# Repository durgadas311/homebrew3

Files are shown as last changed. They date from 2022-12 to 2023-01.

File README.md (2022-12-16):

# homebrew3

This project is for this
[VCFED discussion thread](https://forum.vcfed.org/index.php?threads/homebrew-z80-no-3.1240919/).

Photos of the computer are on this
[Google Drive](https://drive.google.com/drive/folders/1JXV017_ggF-4IG32N2BlPU1Jmj1P-w-M).

Documentation:

 * [Schematics](kicad/homebrew3.pdf)
 * [Layout/BOM](kicad/perfboard-layout.pdf)
 * [Monitor ROM](doc/MonitorROM.pdf)
 * [Simulator Help](https://htmlpreview.github.io/?https://github.com/durgadas311/homebrew3/blob/master/sim/docs/HB3.html)

The "gui" option (or property) is now working.

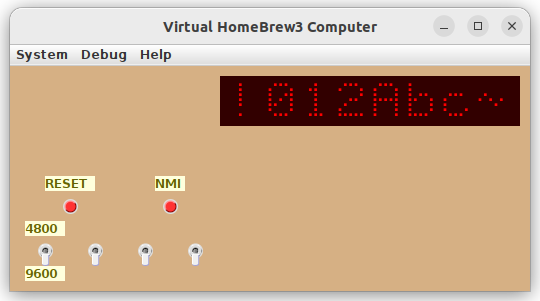
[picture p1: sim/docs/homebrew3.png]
HB3 pic


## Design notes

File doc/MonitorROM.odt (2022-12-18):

Z80 Home Brew #3

Monitor ROM

December 18, 2022

## Overview

The machine consists of a Z80-CPU, 2K EPROM (expandable to 4K), 4K of RAM, two Z80-PIO, one Z80CTC, one Z80-SIO/0, and an HDSP-2111 8-character 5x7 LED dot matrix display. All four PIO channels are wired to a 50-pin FCC connector (P3). Both SIO channels are wired to a DIP14 socket/connector (P4). General-purpose I/O expansion is provided on a pair of DIP14 sockets/connectors (P1, P2). The HDSP-2111 display is wired as an I/O expansion.

The original EPROM for this machine was damaged, and all odd pages (256-byte chunks) are missing (A8 shorted to GND). Half the monitor code is missing, but some things can be reconstructed or restored based how the existing code interacts.

## General Operation

The monitor may be entered from a running program by pressing the NMI button or by executing a RST 1 instruction (0xCF) in the program. In the case of RST 1, the saved PC will point to the RST 1 instruction (not the next instruction). In both cases, the saved PC is printed after a ‘>’ character before entering the monitor loop.

Pressing NMI while running the monitor is similar to RESET.

The monitor prompt is the asterisk (‘*’) character, however that is reconstructed code and there is no indication what the prompt character was originally.

## User Commands

In the following, addr and byte are entered in hexadecimal. [ ] means the parameter is optional. CR means the carriage return key. LF means the line feed key.

### Implemented Commands

The following commands either have code that defines the operation, or can be reasonably determined based on space available and logical deduction.

[addr]CR

print the byte stored at addr, advance addr by 1.

[addr]/

print the word stored at addr, advance addr by 2. Also used after ‘T’ or ‘R’ commands to view subsequent values.

[addr]I

Input bytes starting at addr. Prints current address and current contents and waits for input. Commands are:

[byte]CR

store byte (if entered) in addr, increment addr by 1. CR alone is used to skip to next location without altering contents.

decrement addr by 1.

return to monitor

[addr]G

Go (start execution) at addr or saved PC

P

start execution at PC+1 (for continuing after RST 1 traps).

T

print word at saved SP (top of stack), increment addr by 2. The top of stack will not include the PC that was pushed as part of the NMI or RST 1. The rest of the stack may be viewed by using ‘/’ commands.

Rreg/

print contents of saved register pair. reg is one of: A,B,D,H,A',B',D',H',X,Y,S,P. Increment addr by 2, effectively selecting the next register pair. Successive registers may be viewed by using ‘/’ commands.

H

Host control mode? Appears to accept commands from SIO channel B, as if connected to a remote computer. Remote commands are echoed to console (channel A), unclear what other interaction there is. Or possibly just an alternate set of commands still using the console (current implementation, for testing).

### Unknown Commands

The following commands do not have code.

LF

(unknown)

^

(unknown) “up”?

V

(unknown) “down”?

## Host Control Commands

Host control commands may be prefixed with an octal number. Unclear how data is sent back to host (in octal?). Might still be controlled by console, unclear if any interaction with host.

(unknown)

,

(unknown)

\

(unknown)

LF

(unknown)

CR

(unknown)

S

(unknown)

R

(unknown)

X

Exit Host mode, return to monitor

M

(unknown interaction with PIO-connected device) possible device memory test

/

(unknown)

^

(unknown)

<

(unknown)

>

(unknown)

G

Get 2K bytes from PIO-connected device. Read pairs of 4-bits from PIO2B. Buffer at 1600H. Missing routines to initialize and perform actions between each 4-bits.

P

Put 2K bytes to PIO-connected device. Writes pairs of 4-bits to PIO2A. Buffer at 1600H. Missing routines to initialize and perform actions between each 4-bits.

TBD

enter Terminal mode, with HEX loading enabled.

[addr]TBD

write addr to the PIO-connected device as two 6-bit values on pio1A, strobing pio2B bit 4 for low value and pio2B bit 5 for high value. The value addr is first decremented by 2 and xor’ed with 1. Any bits beyond the 12 are ignored.

## Terminal Mode Operation

The code passes characters both directions between SIO channels A and B. In addition, there is a mode where the stream coming from channel B may contain Intel HEX format data, which is presumably loaded into memory. The console (channel A) user may press Ctrl-] (0x1d, ASCII “GS”) to cause a BREAK condition to be sent to channel B, presumably to disconnect from the host or terminate a program. There is some number of successive Ctrl-] presses required to activate the BREAK feature, to avoid accidental disconnect. At least one other key command seems to exist, possibly to exit terminal mode. Considering the nature of “terminal mode”, this exit key would have been some control character that is not normally used (similar to the BREAK code).

## Hardware Clues in Software

### Device on 50-pin Connector

- Data path seems to be 4-bits wide, output on low bits of PIO2-A and input on low bits of PIO2-B.
- There may be a 6-bit path, sometimes used for address hi/lo, on PIO1-A.
- Capacity seems to be 2K bytes (4K nibbles).
- Addressing seems to be 12-bit, with the LSB selecting the nibble.
  - In one case, the user-entered address is modified before sending: addr = (addr – 2) ^ 1, and 6-bit halves are successively sent to PIO1-A while pulsing PIO2-B bits 4 and 5 (for low and high halves, respectively).
- There seems to be either RAM associated with the device (e.g. a buffered EPROM programmer) or else the device allows plugging in of RAM chips (e.g. an IC tester).
- There is a subset of commands that operate on this device, activated by the ‘H’ command.
- These subcommands use octal, in contrast to the main monitor commands that use hexadecimal. Although, parameters that might be input for various commands may use some other base (the code is missing).
- In some cases, it appears that the PIO RDY outputs are used by the device to latch data, but in one case (at least) PIO2-B bits 4 and 5 are bit-banged to latch data (from PIO1-A). Note that, in order for RDY to be effective, the /STB inputs must also be used.
- The ‘H’ subcommand mode programs PIO1-A, PIO1-B, and PIO2-A in output mode (RDY signals active), and programs PIO2-B in control mode with bits 0-3 as inputs, 4-7 as outputs.

### LED 5x7 Display

- No code has been found that accesses the display. It may have been added for experimentation purposes (vs. being part of the development environment).
- This display is capable of showing eight ASCII characters (full 7-bit decoding).
- The display datecode indicates 1987, while the rest of the parts have datecodes 1977-1981. It is possible that the display is not part of the original equipment. The wire-wrap shows that that device was added last (in that vicinity).
- It is possible that the display was used to mirror console output or show some other status, but that would have to be in the missing code.

### Serial Ports

- SIO-A is the user console. Unclear if that was a hard-copy like ASR-33 or a CRT terminal.
- Under some conditions, SIO-B is connected to a remote system (“terminal mode”).
- The only confirmed code to use SIO-B is the terminal mode loop.
- It is not known if the 4800/9600 switch affects SIO-A or SIO-B. It would depend on what each is connected to, e.g. an ASR-33 on A can only be 110 baud, so 4800/9600 must be SIO-B. But if SIO-B connects to a modem, then 4800/9600 must be for SIO-A (given the time period and modem speeds of that era). The actual data used to program SIO bauds is missing.
- All four toggle switches feed to the handshake inputs on the SIO. The only code known to access those inputs is the test for 4800/9600 done during initialization.
- The original connections to the SIO were via 4-wire modular telephone cable (YEL, GRN, RED, BLK). Channel B is wired reverse from channel A (RxD/TxD).
  - There appears to have been one wire that was passed through directly between port A and Port B, probably a handshake line. Unclear which direction or purpose. ‘?’ below.
  - One port’s cable terminated in a RJ14-M modular connector, the other terminated in a RJ14-F mounted in the terminal box, painted blue. Unclear which port went to which connector. Also unclear how each cable was wired to the RJ14 connector.
  - Port A is wired TxD=YEL, RxD=RED, ?=GRN, GND=BLK.
  - Port B is wired TxD=RED, RxD=YEL, ?=GRN, GND=BLK.
  - It is not known whether the original owner had “standard” RJ14-to-RS232 adapters, or used some custom connections to the end points.

Z80 home Brew #3 – Monitor ROM 6

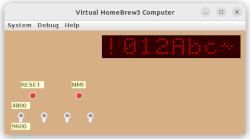
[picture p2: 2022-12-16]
sim/docs/homebrew3-sm.png

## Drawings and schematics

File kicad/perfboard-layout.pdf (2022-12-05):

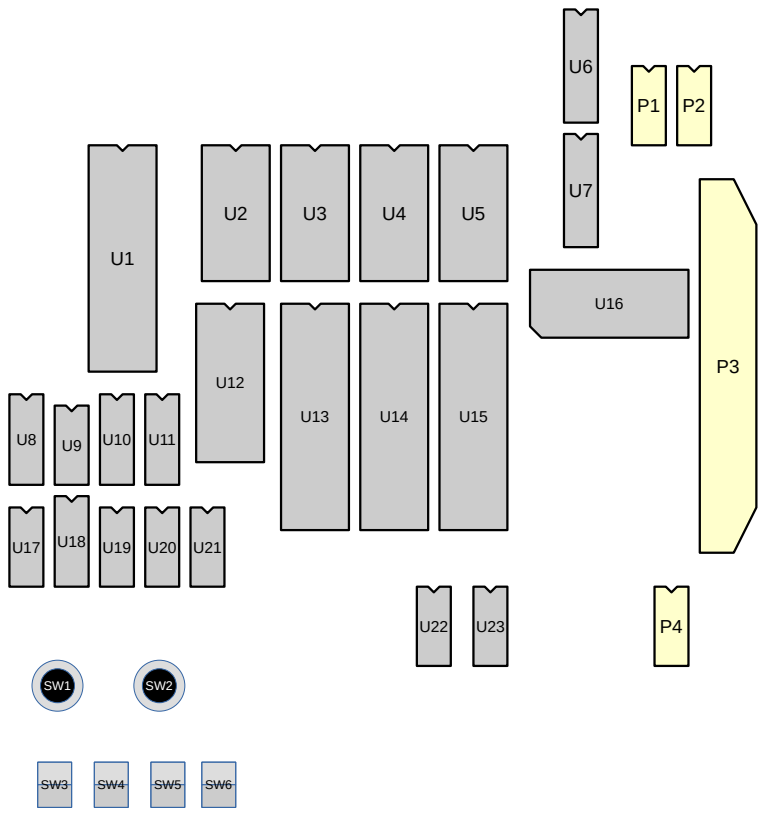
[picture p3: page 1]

U1 | Z80A-CPU
U2 | MK2716 (@0000)
U3 | MK2716 (@0800) – empty
U4 | TMM2016 (@1000)
U5 | TMM2016 (@1800)
U6 | 74LS245
U7 | 74LS245
U8 | 74S163
U9 | 74S04
U10 | 74LS138
U11 | 74LS139
U12 | Z80A-CTC
U13 | Z80A-SIO/0
U14 | Z80A-PIO
U15 | Z80A-PIO
U16 | HDSP-2111 (5x7 8-char display)
U17 | 20.000MHz Oscillator
U18 | Discrete components:
R1: | 1,16 | 330 R
R2: | 2,15 | 33K R
D1: | +3,14 D
R3: | 4,13 | 68 R
C1: | +5,12 C (electrolytic)
| 6,11 | empty
R4: | 7,10 | 5.6K R
| 8,9 | empty
U19 | 74LS14
U20 | 74LS08
U21 | 74LS32
U22 | MC1489
U23 | MC1488
SW1 | SPDT pushbutton – RESET
SW2 | SPDT pushbutton – NMI
SW3 SPDT toggle – 4800/9600 (up/down)
SW4 | SPDT toggle
SW5 | SPDT toggle
SW6 SPDT toggle
P1 | DIP14 socket – I/O expansion
P2 | DIP14 socket – I/O expansion
P3 | FCC50-M – GPIO (Z80A-PIOs)
P4 | DIP14 socket – RS-232

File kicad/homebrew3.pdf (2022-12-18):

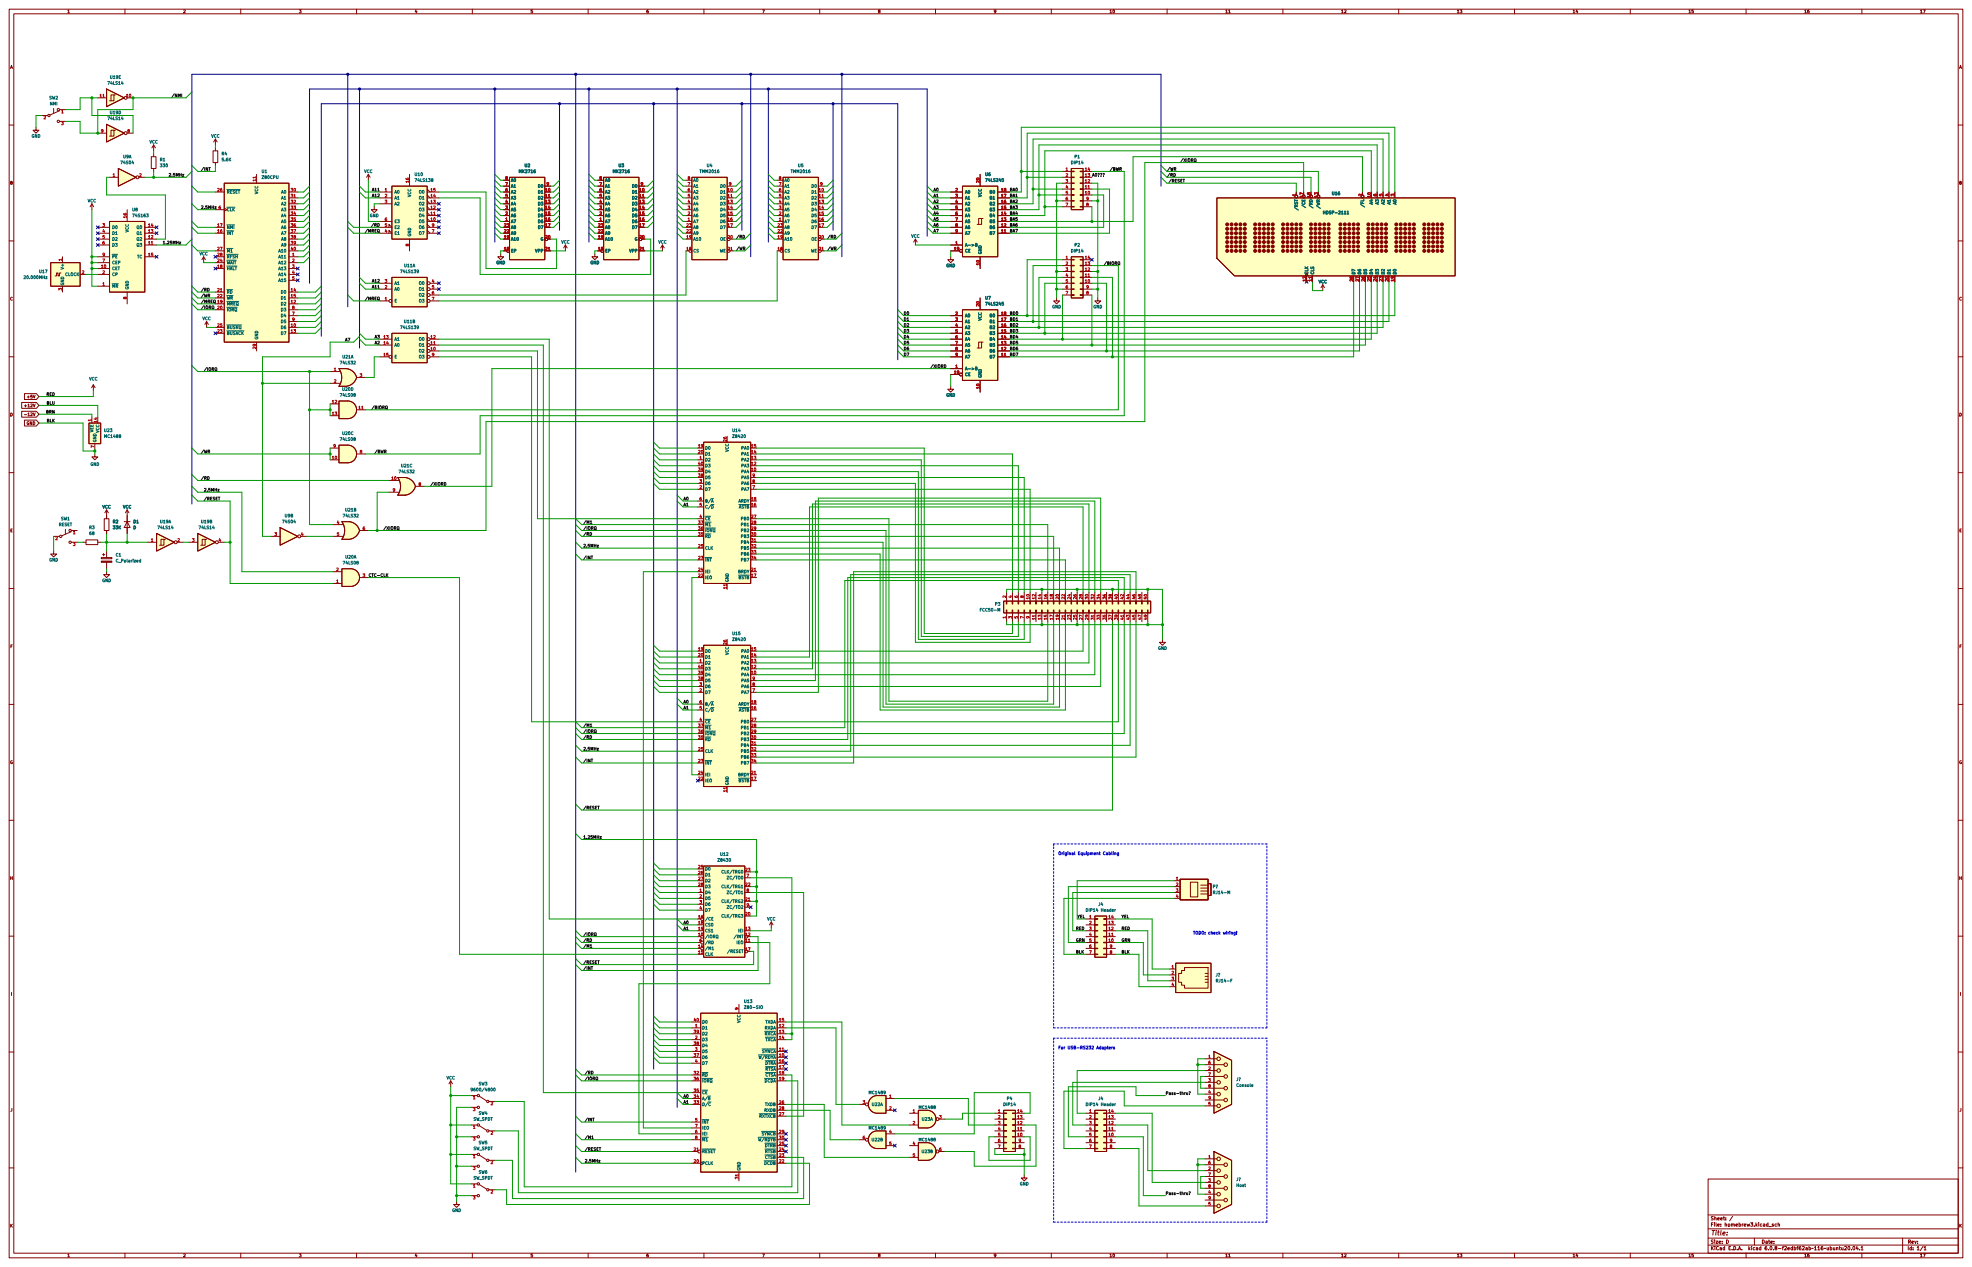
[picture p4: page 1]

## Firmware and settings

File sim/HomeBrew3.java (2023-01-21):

// Copyright 2018 Douglas Miller <durgadas311@gmail.com>

import java.util.Arrays;
import java.util.Vector;
import java.util.Map;
import java.util.HashMap;
import java.io.*;
import java.util.concurrent.Semaphore;
import java.util.concurrent.locks.ReentrantLock;
import java.util.Properties;

import z80core.*;
import z80debug.*;

public class HomeBrew3 implements Computer, ComputerSystem,
			Commander, Interruptor, Runnable {
	private Z80 cpu;
	private Z80SIO sio;
	private long clock;
	private Map<Integer, IODevice> ios;
	private Vector<IODevice> devs;
	private Vector<DiskController> dsks;
	private Vector<InterruptController> intrs;
	private Memory mem = null;
	private boolean running;
	private boolean stopped;
	private Semaphore stopWait;
	private int[] intRegistry;
	private int[] intLines;
	private int intState;
	private int intMask;
	private boolean nmiState;
	private boolean isHalted;
	private boolean sleeping;
	private Vector<ClockListener> clks;
	private CPUTracer trc;
	private StdioDebugger dbg;
	private ReentrantLock cpuLock;

	private int mdmA = 0;
	private int mdmB = 0;

	// Relationship between virtual CPU clock and real time
	private long intervalTicks = 2500;	// 1ms at 2.5MHz
	private long intervalNs = 1000000;	// 1ms
	private long backlogTime = 10000000;	// 10ms backlog limit
	private long backlogNs;

	public HomeBrew3(Properties props) {
		String s;
		intRegistry = new int[8];
		intLines = new int[8];
		Arrays.fill(intRegistry, 0);
		Arrays.fill(intLines, 0);
		intState = 0;
		intMask = 0;
		running = false;
		stopped = true;
		stopWait = new Semaphore(0);
		cpuLock = new ReentrantLock();
		sleeping = false;
		cpu = new Z80(this);
		ios = new HashMap<Integer, IODevice>();
		devs = new Vector<IODevice>();
		dsks = new Vector<DiskController>();
		clks = new Vector<ClockListener>();
		intrs = new Vector<InterruptController>();
		// Do this early, so we can log messages appropriately.
		s = props.getProperty("log");
		if (s != null) {
			String[] args = s.split("\\s");
			boolean append = false;
			for (int x = 1; x < args.length; ++x) {
				if (args[x].equals("a")) {
					append = true;
				}
			}
			try {
				FileOutputStream fo = new FileOutputStream(args[0], append);
				PrintStream ps = new PrintStream(fo, true);
				System.setErr(ps);
			} catch (Exception ee) {}
		}
		s = props.getProperty("configuration");
		if (s == null) {
			System.err.format("No config file found\n");
		} else {
			System.err.format("Using configuration from %s\n", s);
		}
		s = props.getProperty("con_att");
		if (s == null) {
			props.setProperty("con_att", "StdioSerial");
		}

		Memory64K mx = new Memory64K(props, "homebrew3.rom");
		//addDevice(mx);
		mem = mx;
		long clk = 400;	// system clock period, nS
		Z80CTC ctc = new Z80CTC(props, 0x00, clk, -1, this);
		sio = new Z80SIO(props, "con", "sys", 0x04, -1, this);
		Z80PIO pio1 = new Z80PIO(props, null, null, 0x08, 0, this);
		Z80PIO pio2 = new Z80PIO(props, null, null, 0x0c, 1, this);
		addDevice(pio2);
		addDevice(pio1);
		addDevice(sio);
		addDevice(ctc);

		s = props.getProperty("trace");
		trc = new Z80Tracer(props, null, cpu, mem, s);

		s = props.getProperty("debugger");
		if (s != null) {
			dbg = new StdioDebugger(props, this);
		}
	}

	public void setSwitches(int sw, boolean on) {
		int _a = mdmA;
		int _b = mdmB;
		int chA = 0;
		int chB = 0;
		switch (sw) {
		case SwitchProvider.TOGGLE0:
			chA = VirtualUART.SET_CTS;
			break;
		case SwitchProvider.TOGGLE1:
			chA = VirtualUART.SET_DCD;
			break;
		case SwitchProvider.TOGGLE2:
			chB = VirtualUART.SET_CTS;
			break;
		case SwitchProvider.TOGGLE3:
			chB = VirtualUART.SET_DCD;
			break;
		}
		if (chA != 0) {
			if (on) {
				mdmA |= chA;
			} else {
				mdmA &= ~chA;
			}
			if (_a != mdmA) {
				sio.portA().setModem(mdmA);
			}
		}
		if (chB != 0) {
			if (on) {
				mdmB |= chB;
			} else {
				mdmB &= ~chB;
			}
			if (_b != mdmB) {
				sio.portB().setModem(mdmB);
			}
		}
	}

	public void changeSpeed(int x,int y) {
	}

	// ComputerSystem interfaces:
	public void reset() {
		boolean wasRunning = running;
		trc.setTrace("off");
		// TODO: reset other interrupt state? devices should do that...
		intMask = 0;
		clock = 0;
		stop();
		if (false && wasRunning) {
			System.err.format("backlogNs=%d\n", backlogNs);
		}
		backlogNs = 0;
		cpu.reset();
		mem.reset();
		for (int x = 0; x < devs.size(); ++x) {
			devs.get(x).reset();
		}
		if (wasRunning) {
			start();
		}
	}
	public void dmaRead(byte[] buf, int adr, int len) {
		try {
			if (!sleeping) {
				cpuLock.lock(); // might wait for CPU to finish 1mS
			}
			int x = 0;
			while (len > 0 && x < buf.length) {
				buf[x++] = (byte)peek8(adr++);
				--len;
			}
		} finally {
			if (!sleeping) {
				cpuLock.unlock();
			}
		}
	}
	public void dmaWrite(byte[] buf, int adr, int len) {
		try {
			if (!sleeping) {
				cpuLock.lock(); // might wait for CPU to finish 1mS
			}
			int x = 0;
			while (len > 0 && x < buf.length) {
				poke8(adr++, buf[x++] & 0xff);
				--len;
			}
		} finally {
			if (!sleeping) {
				cpuLock.unlock();
			}
		}
	}
	////////////////////////////////////////////////////

	public boolean addDevice(IODevice dev) {
		if (dev == null) {
			System.err.format("NULL I/O device\n");
			return false;
		}
		int base = dev.getBaseAddress();
		int num = dev.getNumPorts();
		if (num <= 0) {
			System.err.format("No ports\n");
			return false;
		}
		for (int x = 0; x < num; ++x) {
			if (ios.get(base + x) != null) {
				System.err.format("Conflicting I/O %02x (%02x)\n", base, num);
				return false;
			}
		}
		devs.add(dev);
		for (int x = 0; x < num; ++x) {
			ios.put(base + x, dev);
		}
		return true;
	}

	public IODevice getDevice(int basePort) {
		IODevice dev = ios.get(basePort);
		return dev;
	}

	public Vector<DiskController> getDiskDevices() {
		return dsks;
	}

	public boolean addDiskDevice(DiskController dev) {
		if (!addDevice(dev)) {
			return false;
		}
		dsks.add(dev);
		return true;
	}

	// These must NOT be called from the thread...
	public void start() {
		stopped = false;
		if (running) {
			return;
		}
		running = true;
		Thread t = new Thread(this);
		t.setPriority(Thread.MAX_PRIORITY);
		t.start();
	}
	public void stop() {
		stopWait.drainPermits();
		if (!running) {
			return;
		}
		running = false;
		// This is safer than spinning, but still stalls the thread...
		try {
			stopWait.acquire();
		} catch (Exception ee) {}
	}
	private void addTicks(int ticks) {
		clock += ticks;
		for (ClockListener lstn : clks) {
			lstn.addTicks(ticks, clock);
		}
	}

	// I.e. admin commands to virtual system...
	public Commander getCommander() {
		return (Commander)this;
	}

	// TODO: these may be separate classes...
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

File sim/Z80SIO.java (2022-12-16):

// Copyright (c) 2017 Douglas Miller <durgadas311@gmail.com>

import java.util.Arrays;
import java.util.Vector;
import java.util.Properties;
import java.io.*;
import java.util.concurrent.Semaphore;
import java.lang.reflect.Constructor;

public class Z80SIO implements IODevice, InterruptController {
	static final int fifoLimit = 10; // should never even exceed 2
	private Interruptor intr;
	private int src;
	private int basePort;
	private String name = null;

	private Z80SIOPort[] ports = new Z80SIOPort[2];
	private int intrs = 0;

	public Z80SIO(Properties props, String pfxA, String pfxB, int base,
			int idx, Interruptor intr) {
		if (idx < 0) {
			name = "Z80SIO";
		} else {
			name = String.format("Z80SIO%d", idx + 1);
		}
		this.intr = intr;
		src = intr.registerINT(0);
		intr.addIntrController(this);
		basePort = base;
		ports[0] = new Z80SIOPort(props, pfxA, 0, null);
		ports[1] = new Z80SIOPort(props, pfxB, 1, ports[0]);
		reset();
	}

	///////////////////////////////
	/// Interfaces for IODevice ///
	public int in(int port) {
		int x = port & 1;
		return ports[x].in(port >> 1);
	}

	public void out(int port, int val) {
		int x = port & 1;
		ports[x].out(port >> 1, val);
	}

	public void reset() {
		intrs = 0;
		intr.lowerINT(0, src);
		ports[0].reset();
		ports[1].reset();
	}
	public int getBaseAddress() {
		return basePort;
	}
	public int getNumPorts() {
		return 4;
	}
	public String getDeviceName() {
		return name;
	}

	private void raiseINT(int idx) {
		int i = intrs;
		intrs |= (1 << idx);
		if (i == 0) {
			intr.raiseINT(0, src);
		}
	}

	private void lowerINT(int idx) {
		int i = intrs;
		intrs &= ~(1 << idx);
		if (i != 0 && intrs == 0) {
			intr.lowerINT(0, src);
		}
	}

	public VirtualUART portA() { return ports[0]; }
	public BaudListener clockA() { return ports[0]; }
	public VirtualUART portB() { return ports[1]; }
	public BaudListener clockB() { return ports[1]; }

	public int readDataBus() {
		if (intrs == 0) {
			return -1;
		}
		int vec = -1;
		// Only Ch B has the vector, but either may interrupt...
		vec = ports[1].readDataBus();
		return vec;
	}

	public boolean retIntr() {
		if (intrs == 0) {
			return false;
		}
		if ((intrs & 1) != 0) {
			ports[0].retIntr();
		} else if ((intrs & 2) != 0) {
			ports[1].retIntr();
		}
		if (intrs == 0) {
			intr.lowerINT(0, src);
		}
		return true;
	}

	class Z80SIOPort implements VirtualUART, BaudListener {
		private java.util.concurrent.LinkedBlockingDeque<Integer> fifo;
		private java.util.concurrent.LinkedBlockingDeque<Integer> fifi;
		private byte[] wr;
		private byte[] rr;

		static final int rr0_rxr_c = 0x01;
		static final int rr0_int_c = 0x02;
		static final int rr0_txp_c = 0x04;
		static final int rr0_dcd_c = 0x08;
		static final int rr0_syn_c = 0x10;
		static final int rr0_cts_c = 0x20;
		static final int rr0_txu_c = 0x40;
		static final int rr0_brk_c = 0x80;

		static final int wr5_dtr_c = 0x80;
		static final int wr5_brk_c = 0x10;
		static final int wr5_rts_c = 0x02;

		private Object attObj;
		private OutputStream attFile;
		private boolean excl = true;
		private long lastTx = 0;
		private long lastRx = 0;
		private long nanoBaud = 0; // length of char in nanoseconds
		private int bits; // bits per character
		private int index;
		private Z80SIOPort chA; // null on Ch A
		private int intrs;
		private int mdms = 0;	// modem inputs, floating
		private boolean rr0Latch = false;
		private int modem = -1;
		private Semaphore wait;

		private SerialDevice io = null;
		private boolean io_in;
		private boolean io_out;

		public Z80SIOPort(Properties props, String pfx, int idx, Z80SIOPort alt) {
			chA = alt;
			attObj = null;
			attFile = null;
			index = idx;
			wait = new Semaphore(0);
			fifo = new java.util.concurrent.LinkedBlockingDeque<Integer>();
			fifi = new java.util.concurrent.LinkedBlockingDeque<Integer>();
			wr = new byte[8];
			rr = new byte[8]; // only 3 useable...
			String s = props.getProperty(pfx + "_att");
			if (s != null && s.length() > 1) {
				if (s.charAt(0) == '>') { // redirect output to file
					attachFile(s.substring(1));
				} else if (s.charAt(0) == '!') { // pipe to/from program
					attachPipe(s.substring(1));
				} else {
					attachClass(props, s);
				}
			}
		}

		private void attachFile(String s) {
			String[] args = s.split("\\s");
			setupFile(args, 0);
		}

		private void setupFile(String[] args, int start) {
			boolean append = false;
			for (int x = start + 1; x < args.length; ++x) {
				if (args[x].equals("a")) {
					append = true;
				} else if (args[x].equals("+")) {
					excl = false;
				}
			}
			if (args[start].equalsIgnoreCase("syslog")) {
				attFile = System.err;
				excl = false;
			} else try {
				attFile = new FileOutputStream(args[start], append);
				if (excl) {
					setModem(VirtualUART.SET_CTS | VirtualUART.SET_DSR);
				}
			} catch (Exception ee) {
				System.err.format("Invalid file in attachment: %s\n", args[start]);
				return;
			}
		}

		private void attachPipe(String s) {
			System.err.format("Pipe attachments not yet implemented: %s\n", s);
		}

		private void attachClass(Properties props, String s) {
			String[] args = s.split("\\s");
			for (int x = 1; x < args.length; ++x) {
				if (args[x].startsWith(">")) {
					excl = false;
					args[x] = args[x].substring(1);
					setupFile(args, x);
					// TODO: truncate args so Class doesn't see?
				}
			}
			Vector<String> argv = new Vector<String>(Arrays.asList(args));
			// try to construct from class...
			try {
				Class<?> clazz = Class.forName(args[0]);
				Constructor<?> ctor = clazz.getConstructor(
						Properties.class,
						argv.getClass(),
						VirtualUART.class);
				// funky "new" avoids "argument type mismatch"...
				Object obj = ctor.newInstance(
						props,
						argv,
						(VirtualUART)this);
				if (attach(obj)) {
					System.err.format("%s-%c attached to \"%s\"\n",
						name, index + 'A', s);
				} else {
					System.err.format("%s-%c failed to attached\n",
						name, index + 'A');
				}
			} catch (Exception ee) {
				System.err.format("Invalid class in attachment: %s\n", s);
				return;
			}
		}

		// Conditions affecting interrupts have changed, ensure proper signal.
		private void chkIntr() {
			int intr = 0;
			// TODO: determine interrupt status
			// TODO: "first char" handling needed?
			if ((wr[1] & 0x18) != 0 && (rr[0] & rr0_rxr_c) != 0) {
				intr |= 1;
			}
			if ((wr[1] & 0x02) != 0 && (rr[0] & rr0_txp_c) != 0) {
				intr |= 2;
			}
			// CTS/DCD detection done in setModem()
			if ((wr[1] & 0x01) != 0 && (rr[0] & 0xd0) != 0) {
				intr |= 4;
			}
			// TODO: special receive condition detection
			// TODO: exclude parity if bit set...
			if ((wr[1] & 0x18) != 0 && (rr[1] & 0xf0) != 0) {
				intr |= 8;
			}
			// TODO: check diffs?
			updateIntr(intr);
		}
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

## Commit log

2022-11-30 Initial files for project to reverse-engineer a "home brew" Z80 system. https://forum.vcfed.org/index.php?threads/homebrew-z80-no-3.1240919/
    [homebrew3.kicad_pcb, homebrew3.kicad_sch]
2022-12-01 Corrections for Z80-SIO/0 in schematic, and I/O decoding signals.
    [homebrew3.kicad_sch]
2022-12-01 Add CTC-SIO connections, misc cleanup.
    [homebrew3.kicad_sch]
2022-12-02 Complete more of schematic, incl. assumed PIO connections
    [homebrew3.kicad_sch]
2022-12-02 Complete more of schematic
    [homebrew3.kicad_sch]
2022-12-02 Add more connections and cleanup to schematic
    [homebrew3.kicad_sch]
2022-12-03 Complete more implied connections on schematic
    [homebrew3.kicad_sch]
2022-12-05 Minor cleanup of schematic/BOM
    [homebrew3.kicad_sch]
2022-12-14 Fix bug where logout/exit of program spewed chars to UART
    [ProgramSerial.java]
2022-12-16 Fixup GUI, incl HDSP-2111 display and switches
    [GEN5x7.sdf]
2022-12-16 Cleanup handling of toggle switches, enumeration of periph chips. Add help text and fix intermittent problem displaying help window.
    [HomeBrew3.java, ProgramSerial.java, Z80SIO.java]
2022-12-17 Fix CPU clock speed, add example program for HDSP-2111.
    [HomeBrew3.java]
2022-12-18 Add examples of wiring to SIO A/B, add system power connections. Cleanup custom symbols.
    [homebrew3.kicad_sch]
2023-01-21 Convert to using z80debug for trace/disassemble
